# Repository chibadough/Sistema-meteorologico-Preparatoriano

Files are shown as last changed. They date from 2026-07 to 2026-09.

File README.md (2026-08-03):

# Sistema-meteorologico-Preparatoriano

Código de una estación meteorológica Balun Canan desarrollada por un grupo de estudiantes de preparatoria como parte de un proyecto STEM presentado para la Fundación MetLife y el movimiento STEM.

---

## Desarrolladores

Hardware (Programador Arduino, Diseño de circuitos y modelo 3D): ChibaDough (Juan Espinosa).
Software (Programador del sistema de almacenamiento de datos en SQL con Python en Raspberry Pi 4): Roberto Bonifaz.

---
# Español

## Descripción del Proyecto

Este proyecto consiste en una estación meteorológica educativa diseñada y programada por estudiantes de preparatoria con el objetivo de fomentar el aprendizaje científico, el monitoreo ambiental y el desarrollo tecnológico.

El sistema recopila datos atmosféricos y ambientales en tiempo real utilizando sensores compatibles con Arduino.  
Su propósito es demostrar cómo los sistemas embebidos de bajo costo pueden utilizarse para monitoreo climático, experimentación científica e investigación educativa.

La estación fue desarrollada como un prototipo funcional capaz de medir condiciones ambientales tanto en exteriores como en zonas de sombra para realizar comparaciones y pruebas.

Este repositorio contiene el código fuente utilizado para leer sensores, procesar información ambiental y mostrar telemetría mediante comunicación Serial.

---

## Características

- Monitoreo de presión atmosférica mediante BME280
- Medición de temperatura ambiental
- Monitoreo de humedad relativa
- Medición de velocidad del viento y direccion.
- Mediciones pluviales
- Comparación entre temperatura exterior y en sombra
- Salida de telemetría en tiempo real por Serial
- Arquitectura modular basada en Arduino

---

## Tecnologías y Hardware

El proyecto utiliza:

- Microcontrolador compatible con Arduino
- Sensor atmosférico BME280
- Sensores DHT11 de humedad y temperatura
- Bus de comunicación I2C
- Salida Serial para telemetría

---

## Librerías Utilizadas

Este proyecto utiliza las siguientes librerías de Arduino:

- `Wire.h`
- `Adafruit_BME280`
- `Adafruit_Sensor`
- `DHT`
- `DHT_U`

---

## Créditos

Agradecimientos especiales a los desarrolladores y mantenedores de las librerías de código abierto utilizadas en este proyecto:

- [Adafruit BME280 Library](https://github.com/adafruit/Adafruit_BME280_Library)
- [Adafruit Unified Sensor Library](https://github.com/adafruit/Adafruit_Sensor)
- [DHT Sensor Library by Adafruit](https://github.com/adafruit/DHT-sensor-library)
- [Arduino Wire Library Documentation](https://www.arduino.cc/reference/en/language/functions/communication/wire/)

Este proyecto no sería posible sin la comunidad open-source de Arduino y STEM.

---

## Propósito Educativo

Este repositorio fue creado principalmente para:

- Educación STEM
- Monitoreo ambiental
- Aprendizaje de sistemas embebidos
- Práctica de integración de sensores
- Experimentación científica
- Proyectos de ingeniería a nivel preparatoria

El proyecto fue desarrollado como un prototipo educativo, por lo que algunos sistemas e implementaciones pueden permanecer experimentales o simplificados.

---

## Equipo y Colaboración

Esta estación meteorológica fue desarrollada colaborativamente por un grupo de estudiantes de preparatoria interesados en ciencia, ingeniería, programación y tecnologías ambientales.

El proyecto fue creado como parte de una iniciativa educativa relacionada con:

- El movimiento STEM
- Programas de innovación científica y tecnológica
- Desarrollo de prototipos educativos para la Fundación MetLife

---

## Contribuciones

Las sugerencias, mejoras y comentarios son bienvenidos.

Posibles mejoras futuras incluyen:

- Dashboard web para monitoreo climático
- Sensores más precisos
- Soporte para tarjetas SD

---

# English

## Project Description

This project is the Balun Canan weather station designed and programmed by high school students to promote scientific learning, environmental monitoring, and STEM development.

The system collects real-time atmospheric and environmental data using Arduino-compatible sensors.  
Its purpose is to demonstrate how low-cost embedded systems can be used for climate monitoring, scientific experimentation, and educational research.

The station was developed as a functional prototype capable of measuring environmental conditions both outdoors and in shaded areas for comparison and testing purposes.

This repository contains the source code used to read sensor data, process environmental information, and display telemetry through Serial communication.

---

## Developers

Hardware (Arduino programming, circuit design, and 3D modeling): ChibaDough (Juan Espinosa).
Software (Programming the SQL data storage system using Python on Raspberry Pi 4): Roberto Bonifaz.

---

## Features

- Atmospheric pressure monitoring using BME280
- Environmental temperature measurement
- Relative humidity monitoring
- Wind speed and direction measurement
- Rainfall measurement
- Outdoor and shaded temperature comparison
- Real-time Serial telemetry output
- Arduino-based modular architecture

---

## Technologies and Hardware

The project uses:

- Arduino-compatible microcontroller
- BME280 atmospheric pressure sensor
- DHT11 humidity and temperature sensors
- I2C communication bus
- Serial telemetry output

---

## Libraries Used

This project uses the following Arduino libraries:

- `Wire.h`
- `Adafruit_BME280`
- `Adafruit_Sensor`
- `DHT`
- `DHT_U`

---

## Credits

Special thanks to the developers and maintainers of the open-source libraries used in this project:

- [Adafruit BME280 Library](https://github.com/adafruit/Adafruit_BME280_Library)
- [Adafruit Unified Sensor Library](https://github.com/adafruit/Adafruit_Sensor)
- [DHT Sensor Library by Adafruit](https://github.com/adafruit/DHT-sensor-library)
- [Arduino Wire Library Documentation](https://www.arduino.cc/reference/en/language/functions/communication/wire/)

This project would not be possible without the open-source Arduino and STEM communities.

---

## Educational Purpose

This repository was created mainly for:

- STEM education
- Environmental monitoring
- Embedded systems learning
- Sensor integration practice
- Scientific experimentation
- High school engineering projects

The project was developed as an educational prototype, so some systems and implementations may remain experimental or simplified.

---

## Team and Collaboration

This weather station was developed collaboratively by a group of high school students interested in science, engineering, programming, and environmental technologies.

The project was created as part of an educational initiative connected to:

- The STEM movement
- Scientific and technological innovation programs
- Educational prototype development for the MetLife Foundation

---

## Contributions

Suggestions, improvements, and feedback are welcome.

Possible future improvements include:

- Online weather monitoring dashboard
- More accurate sensors
- SD card storage support

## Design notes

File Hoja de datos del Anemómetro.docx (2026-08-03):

Sistema de Medición con Anemómetro

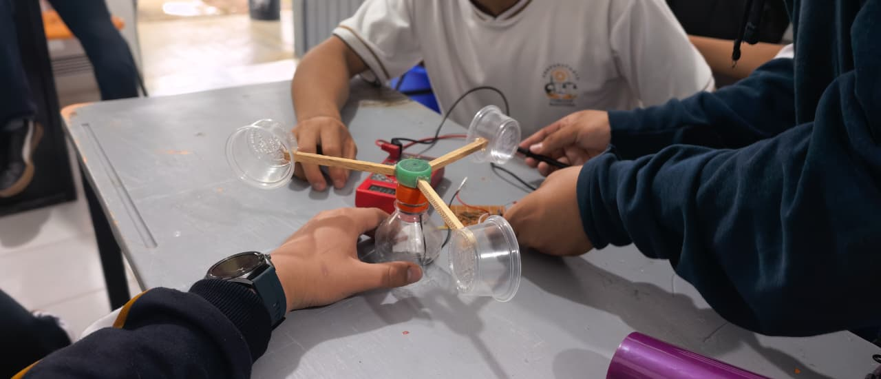
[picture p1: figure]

1. Resumen

Este documento especifica la integración del anemómetro analógico basado en un motor electrico para la medición de la velocidad del aire. A partir de los datos experimentales capturados (AnlogoutAnemometro vs VelAire), se aplica la función de transferencia definida para calcular directamente la velocidad del viento en función de la lectura analógica.

2. Datos de Calibración Registrados

De acuerdo con las mediciones experimentales del archivo anemometro.xlsx:

Índice | Lectura Analógica (l1 / AnlogoutAnemometro) | Velocidad del Aire (VelAire - KM/H)
1 | 13 | 28.2
2 | 17 | 37.7
3 | 23 | 44.0
4 | 27 | 46.1

3. Función de Transferencia / Ecuación del Sensor

La conversión de la señal analógica leída por el microcontrolador a la velocidad del aire utiliza la siguiente ecuación:

vel=0.78⋅l1-5.46

Donde:

vel: Velocidad del aire calculada.

Pendiente ( m ): 0.78

Término independiente ( b ): -5.46

3.1 Termino Independiente.

La aplicación de anemómetros basados en motores es practico y barato, pero puede tener ciertas implicaciones. Como voltajes parásitos mientras el anemómetro está en reposo, el termino independiente (b) es una resta que se hace midiendo el pico máximo de ese voltaje para que cuando eso suceda represente 0. No es necesario, pero hay que tomarlo en cuenta. Como también que gracias al termino independiente, pueden representarse valores negativos. Así que, si no es muy necesario no lo hagas, y si lo vas a colocar, asegura de promediar cada 10 valores o reducir la velocidad de muestreo para que solo se represente valores congruentes al tanteo.

4. Código de Implementación (Arduino / Microcontroladores)

A continuación se presenta el código de lectura y cálculo estructurado utilizando la función del anemómetro:

C++

/*

* Documentación de Código: Medición de Velocidad con Anemómetro

* Ecuación aplicada: vel = 0.78 * l1 - 5.46

*/

// Definición de Pines

const int Ane = A0; // Pin de entrada analógica del anemómetro

// Variables de medición

int l1 = 0; // Valor bruto leído por analogRead

float vel = 0.0; // Velocidad calculada

void setup() {

Serial.begin(115200);

pinMode(Ane, INPUT);

}

void loop() {

// 1. Lectura de la entrada analógica

l1 = analogRead(Ane);

// 2. Aplicación de la función de transferencia

vel = 0.78 * l1 - 5.46;

// 3. Imprimir resultados por Puerto Serie

Serial.print("Lectura ADC (l1): ");

Serial.print(l1);

Serial.print(" | Velocidad: ");

Serial.print(vel, 2);

Serial.println(" km/h");

delay(1000); // Frecuencia de actualización

}

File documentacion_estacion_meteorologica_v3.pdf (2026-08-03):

# Documentación Técnica del Proyecto

Estación Meteorológica Educativa Integrada (Arduino + Raspberry Pi + MySQL)

Proyecto: Monitoreo Ambiental
STEM

Nivel: Preparatoria /
Bachillerato

Arquitectura: Arduino (Adquisición) & Python/MySQL (Procesamiento)

### 1. Resumen General del Proyecto

Descripción: Este proyecto consiste en una estación meteorológica educativa diseñada y programada por estudiantes de preparatoria con el objetivo de fomentar el aprendizaje científico, el monitoreo ambiental y el desarrollo tecnológico.

El sistema recopila datos atmosféricos y ambientales en tiempo real utilizando un microcontrolador Arduino para la captura de variables analógicas/digitales y una computadora de placa única (Raspberry Pi/Linux) para el cómputo avanzado, almacenamiento persistente en base de datos MySQL y registro local CSV.

### 2. Objetivos y Alcance

Educativo & STEM: Demostrar cómo los sistemas embebidos de bajo costo pueden utilizarse para monitoreo climático, experimentación científica e investigación en el aula.

Redundancia y Robustez: Implementar tolerancia a fallos en sensores críticos (como conmutación automática entre sensores DHT11 primario y secundario).

Medición Multivariable: Medición en exteriores y sombra de temperatura, humedad, presión atmosférica, velocidad del viento, precipitación pluvial acumulada y calidad del aire (PPM).

Integración de Software: Protocolo de comunicación Serial entre microcontrolador y servidor Python con persistencia en MySQL (balun_canan).

•

•

•

•

Estación Meteorológica Educativa | Proyecto STEM | Página 1 de 6

### 3. Arquitectura del Hardware y Sensores

Componente / Sensor | Interfaz / Pin | Variable Medida | Función / Observaciones
Arduino Microcontroller | Serial USB (9600 baud) | Adquisición en tiempo real | Lee sensores de campo, procesa pulsos e interrupciones, envía trama CSV por Serial.
BME280 (I2C) | I2C (0x76 / Bus 1) | Temp (°C), Presión (hPa), Humedad (%) | Sensor de alta precisión presente en módulo Arduino y servidor Raspberry Pi.
DHT11 (x2) | Digital Pin 5 (Pri) / Pin 8 (Sec) | Temperatura / Humedad Relativa | Sistema de respaldo con reinicio de alimentación mediante transistores/relés (Pins 7 y 4).
Anemómetro Analógico | Pin Analógico A3 | Velocidad del Viento (m/s o km/h) | Ecuación de calibración lineal aplicada: vel = 0.78 × l1 − 5.46.
Pluviómetro de Balancín | Pin Digital 3 (INT) | Precipitación acumulada (mm) | Mapeo por interrupción (FALLING). Calibrado a 0.3 mm/pulso con anti-rebote (300 ms).
Sensor de Lluvia | Pin Analógico A2 | Detección cualitativa de lluvia | Identifica inicio de lluvia (≥200) o lluvia definitiva (≥600).
MQ-135 | Pin Analógico A1 | Calidad del aire / Gases (PPM) | Cálculo de concentración de gases compensado por temperatura y humedad.

### 4. Código Arduino (`estacion_meteorologica.ino`)

Arduino C++ - Captura y Control de Sensores

#include <MQ135.h>

#include <Adafruit_BME280.h>

#include <Wire.h>

#include <DHT.h>

// Definición de Pines
const int pinV = 7;
const int pinV2 = 4;
const int Ane = A3;
const int sensorA = A2;
const int pluv = 3;
#define PIN_MQ135 A1

#define DHTPIN 5

#define DHTPIN1 8

#define DHTTYPE DHT11

DHT dht(DHTPIN, DHTTYPE);
DHT dht1(DHTPIN1, DHTTYPE); Adafruit_BME280 bme;
MQ135 mq135_sensor(PIN_MQ135);

// Variables Pluviómetro
volatile int contadorPluv = 0;
volatile unsigned long ultimoPulso = 0; volatile unsigned long ultimoPulsoReal = 0; const float mmPulso = 0.3;
const int umbralTiempo = 300; // Anti-rebote (ms)

bool advertencia1 = false;

Estación Meteorológica Educativa | Proyecto STEM | Página 2 de 6

bool advertencia2 = false;

void setup() {
Serial.begin(9600);
dht.begin();
dht1.begin();
Wire.begin();

bme.begin(0x76);

pinMode(pinV, OUTPUT);
pinMode(pinV2, OUTPUT);
pinMode(Ane, INPUT);
pinMode(sensorA, INPUT);
pinMode(pluv, INPUT_PULLUP);

digitalWrite(pinV, HIGH);
digitalWrite(pinV2, HIGH);

attachInterrupt(digitalPinToInterrupt(pluv), contarLluvia, FALLING); }

void contarLluvia() {
unsigned long ahora = millis();
if (ahora - ultimoPulso > umbralTiempo) { contadorPluv++;
ultimoPulso = ahora;
ultimoPulsoReal = ahora;
}
}

void loop() {
float lecturA = analogRead(sensorA);

noInterrupts();
int pulsos = contadorPluv;
unsigned long ultimo = ultimoPulsoReal; interrupts();

if (millis() - ultimo > 30000UL) { noInterrupts();
contadorPluv = 0;
interrupts();
pulsos = 0;
}

float mmTotal = pulsos * mmPulso;

// Manejo de Respaldo DHT11
float tem1 = dht.readTemperature();
float hum1 = dht.readHumidity();

if ((isnan(tem1) || isnan(hum1)) && !advertencia1) { advertencia1 = true;
Serial.println("Reiniciando DHT11 primario..."); digitalWrite(pinV, LOW);
delay(2000);
digitalWrite(pinV, HIGH);
delay(2000);
tem1 = dht.readTemperature();
hum1 = dht.readHumidity();
} else if ((isnan(tem1) || isnan(hum1)) && advertencia1 && !advertencia2) { Serial.println("Cambiando a DHT11 de repuesto...");
advertencia2 = true;
digitalWrite(pinV2, HIGH);
tem1 = dht1.readTemperature();
hum1 = dht1.readHumidity();
Estación Meteorológica Educativa | Proyecto STEM | Página 3 de 6

} else if (isnan(tem1) || isnan(hum1)) { Serial.println("PROBLEMA CON DHT11: REVISAR"); } else {
digitalWrite(pinV, HIGH);
digitalWrite(pinV2, HIGH);
}

float temp = bme.readTemperature(); float pres = bme.readPressure() / 100.0;

int l1 = analogRead(Ane);
float vel = 0.78 * l1 - 5.46;
if (vel < 0) vel = 0; // Evitar valores negativos por descalibración en reposo

float ppm = mq135_sensor.getCorrectedPPM(temp, hum1);

// Formato Serial CSV: Temp_BME, Temp_DHT, Presion, Vel_Viento, Precipitacion, Humedad_DHT, PPM Serial.print(temp); Serial.print(",");
Serial.print(tem1); Serial.print(",");
Serial.print(pres); Serial.print(",");
Serial.print(vel); Serial.print(","); Serial.print(mmTotal); Serial.print(","); Serial.print(hum1); Serial.print(","); Serial.println(ppm);

delay(5000);
}

### 5. Código Python (`programa_6.py`)

Python 3 - Cliente de Procesamiento, CSV y MySQL

import time
from datetime import datetime
import math
import os
import serial
from smbus2 import SMBus
from bme280 import BME280
import mysql.connector

# ===================================== # CÁLCULOS METEOROLÓGICOS

# =====================================

def punto_rocio(temp, hum):
a = 17.27
b = 237.7
alpha = ((a * temp) / (b + temp)) + math.log(hum / 100.0) return (b * alpha) / (a - alpha)

def sensacion_termica(temp, hum):
return (-8.784695 +
1.61139411 * temp +
2.338549 * hum -
0.14611605 * temp * hum -
0.012308094 * (temp**2) -
0.016424828 * (hum**2) +
0.002211732 * (temp**2) * hum + 0.00072546 * temp * (hum**2) -0.000003582 * (temp**2) * (hum**2))

# Configuración de Sensores

bus = SMBus(1)
Estación Meteorológica Educativa | Proyecto STEM | Página 4 de 6

bme280 = BME280(i2c_dev=bus)

# Conexión Base de Datos

db_pass = os.environ.get("DB_PASSWORD", "3and1D0*") db = mysql.connector.connect(
host="localhost",
user="root",
password=db_pass,
database="balun_canan"
)
cursor = db.cursor()

# Conexión Serial Arduino

try:
ser = serial.Serial('/dev/ttyACM0', 9600, timeout=2) time.sleep(2)
except Exception as e:
print(f" Error al abrir puerto Serial: {e}")
ser = None

def leer_arduino():
if ser is None:
return None, None, None, None, None, None, None

try:
line = ser.readline().decode('utf-8').strip() if line:
valores = line.split(',')
if len(valores) == 7:
temp_A = float(valores[0]) temp_ext_A = float(valores[1]) presion_A = float(valores[2]) anemometro = float(valores[3]) precipitacion = float(valores[4])
humedad_A = float(valores[5])
ppm_A = float(valores[6])
return temp_A, temp_ext_A, presion_A, anemometro, precipitacion, humedad_A, ppm_A else:
print(f" Trama incompleta. Recibidos: {len(valores)} campos")
except Exception as e:
print(f" Error lectura Serial: {e}")

return None, None, None, None, None, None, None

# Bucle Principal

print('Comienzo de lectura de estación meteorológica...') contador = 0

with open('datosa.csv', 'a', buffering=1) as f:
while True:
try:
temperatura = bme280.get_temperature() presion = bme280.get_pressure()
humedad = bme280.get_humidity()

dew = punto_rocio(temperatura, humedad)
heat = sensacion_termica(temperatura, humedad)

temp_A, temp_ext_A, presion_A, anemometro, precipitacion, humedad_A, ppm_A = leer_arduino()

now = datetime.now()
fecha_hora = now.strftime("%Y-%m-%d %H:%M:%S")
print(f"[{fecha_hora}] Local BME280: {temperatura:.2f}°C | {presion:.2f} hPa | {humedad:.2f}%")
print(f" | → Rocío: {dew:.2f}°C | Sensación: {heat:.2f}°C")
print(f" | → Arduino: T={temp_A}, TExt={temp_ext_A}, P={presion_A}, Wind={anemometro},
Rain={precipitacion}")
Estación Meteorológica Educativa | Proyecto STEM | Página 5 de 6

if -40 < temperatura < 85 and 300 < presion < 1100: f.write(f"{fecha_hora},{temperatura:.2f},{presion:.2f},{humedad:.2f},{dew:.2f},{heat:.2f}," f"{temp_A},{temp_ext_A},{presion_A},{anemometro},{precipitacion},{humedad_A},{ppm_A} \n")

db.ping(reconnect=True)
sql = ("INSERT INTO Datos_Arduino "
"(fecha, temperatura, presion, humedad, punto_rocio, sensacion_termica, " "temp_A, temp_ext_A, presion_A, anemometro, precipitacion, humedad_A, ppm_A) " "VALUES (%s, %s, %s, %s, %s, %s, %s, %s, %s, %s, %s, %s, %s)")

valores_db = (fecha_hora, temperatura, presion, humedad, dew, heat,
temp_A, temp_ext_A, presion_A, anemometro, precipitacion, humedad_A, ppm_A)

cursor.execute(sql, valores_db)
contador += 1
if contador >= 10:
db.commit()
print(" Lote de 10 registros guardado en MySQL") contador = 0

except Exception as e:
print(" Error general en bucle:", e)

time.sleep(60) # Intervalo de lectura sugerido: 60 segundos

### 6. Guía de Instalación y Puesta en Marcha

Configuración en Arduino: Instalar las librerías MQ135, Adafruit_BME280 y DHT en el IDE de Arduino y compilar el archivo .ino.

Creación de Base de Datos MySQL:

CREATE DATABASE balun_canan;
USE balun_canan;

CREATE TABLE Datos_Arduino (
id INT AUTO_INCREMENT PRIMARY KEY, fecha DATETIME,
temperatura FLOAT,
presion FLOAT,
humedad FLOAT,
punto_rocio FLOAT,
sensacion_termica FLOAT,
temp_A FLOAT,
temp_ext_A FLOAT,
presion_A FLOAT,
anemometro FLOAT,
precipitacion FLOAT,
humedad_A FLOAT,
ppm_A FLOAT
);

Ejecución del Servicio en Python:

pip install smbus2 matrix-bme280 mysql-connector-python pyserial python3 programa_6.py

1.

2.

3.

Estación Meteorológica Educativa | Proyecto STEM | Página 6 de 6

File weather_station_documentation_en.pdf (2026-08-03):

# Technical Project Documentation

Integrated Educational Weather Station (Arduino + Raspberry Pi + MySQL)

Project: Environmental STEM
Monitoring

Level: High School / K-12
STEM

Architecture: Arduino (Acquisition) & Python/MySQL (Processing)

### 1. Project Overview

Description: This project consists of an educational weather station designed and programmed by high school students to foster scientific learning, environmental monitoring, and technological development.

The system collects real-time atmospheric and environmental data using an Arduino microcontroller for analog/ digital sensor reading, along with a single-board computer (Raspberry Pi/Linux) for advanced computation, persistent storage in a MySQL database, and local CSV logging.

### 2. Objectives and Scope

Educational & STEM: Demonstrate how low-cost embedded systems can be utilized for climate monitoring, scientific experimentation, and classroom research.

Redundancy & Robustness: Implement fault tolerance for critical sensors (such as automatic failover switching between primary and backup DHT11 sensors).

Multivariable Measurement: Outdoor and shaded monitoring of temperature, humidity, atmospheric pressure, wind speed, accumulated rainfall, and air quality (PPM).

Software Integration: Serial communication protocol between the microcontroller and the Python server with data persistence in MySQL (balun_canan).

•

•

•

•

Educational Weather Station | STEM Project | Page 1 of 6

### 3. Hardware Architecture and Sensors

Component / Sensor | Interface / Pin | Measured Variable | Function / Remarks
Arduino Microcontroller | Serial USB (9600 baud) | Real-time acquisition | Reads field sensors, handles pulses and interrupts, sends CSV frame over Serial.
BME280 (I2C) | I2C (0x76 / Bus 1) | Temp (°C), Pressure (hPa), Humidity (%) | High-precision sensor located on both the Arduino module and the Raspberry Pi server.
DHT11 (x2) | Digital Pin 5 (Pri) / Pin 8 (Sec) | Temperature / Relative Humidity | Backup system with power reset controlled via transistors/relays (Pins 7 and 4).
Analog Anemometer | Analog Pin A3 | Wind Speed (m/s or km/ h) | Linear calibration equation applied: vel = 0.78 × l1 − 5.46.
Tipping Bucket Rain Gauge | Digital Pin 3 (INT) | Accumulated Rainfall (mm) | Mapped via hardware interrupt (FALLING). Calibrated to 0.3 mm/pulse with debouncing (300 ms).
Rainfall Sensor | Analog Pin A2 | Qualitative rain detection | Identifies rain onset (≥200) or definitive rain (≥600).
MQ-135 | Analog Pin A1 | Air Quality / Gas Concentration (PPM) | Gas concentration calculation compensated for ambient temperature and humidity.

### 4. Arduino Source Code (`estacion_meteorologica.ino`)

Arduino C++ - Sensor Acquisition and Control

#include <MQ135.h>

#include <Adafruit_BME280.h>

#include <Wire.h>

#include <DHT.h>

// Pin Definitions
const int pinV = 7;
const int pinV2 = 4;
const int Ane = A3;
const int sensorA = A2;
const int pluv = 3;
#define PIN_MQ135 A1

#define DHTPIN 5

#define DHTPIN1 8

#define DHTTYPE DHT11

DHT dht(DHTPIN, DHTTYPE);
DHT dht1(DHTPIN1, DHTTYPE); Adafruit_BME280 bme;
MQ135 mq135_sensor(PIN_MQ135);

// Rain Gauge Variables
volatile int contadorPluv = 0;
volatile unsigned long ultimoPulso = 0;
volatile unsigned long ultimoPulsoReal = 0;
const float mmPulso = 0.3;
const int umbralTiempo = 300; // Debounce threshold (ms)

bool advertencia1 = false;

bool advertencia2 = false;

void setup() {
Serial.begin(9600);
dht.begin();
dht1.begin();
Wire.begin();

bme.begin(0x76);

pinMode(pinV, OUTPUT);
pinMode(pinV2, OUTPUT);
pinMode(Ane, INPUT);
pinMode(sensorA, INPUT);
pinMode(pluv, INPUT_PULLUP);

digitalWrite(pinV, HIGH);
digitalWrite(pinV2, HIGH);

attachInterrupt(digitalPinToInterrupt(pluv), contarLluvia, FALLING); }

void contarLluvia() {
unsigned long ahora = millis();
if (ahora - ultimoPulso > umbralTiempo) { contadorPluv++;
ultimoPulso = ahora;
ultimoPulsoReal = ahora;
}
}

void loop() {
float lecturA = analogRead(sensorA);

noInterrupts();
int pulsos = contadorPluv;
unsigned long ultimo = ultimoPulsoReal; interrupts();

if (millis() - ultimo > 30000UL) { noInterrupts();
contadorPluv = 0;
interrupts();
pulsos = 0;
}

float mmTotal = pulsos * mmPulso;

// DHT11 Backup System Handling
float tem1 = dht.readTemperature();
float hum1 = dht.readHumidity();

if ((isnan(tem1) || isnan(hum1)) && !advertencia1) { advertencia1 = true;
Serial.println("Resetting primary DHT11..."); digitalWrite(pinV, LOW);
delay(2000);
digitalWrite(pinV, HIGH);
delay(2000);
tem1 = dht.readTemperature();
hum1 = dht.readHumidity();
} else if ((isnan(tem1) || isnan(hum1)) && advertencia1 && !advertencia2) { Serial.println("Switching to backup DHT11...");
advertencia2 = true;
digitalWrite(pinV2, HIGH);
tem1 = dht1.readTemperature();
hum1 = dht1.readHumidity();

} else if (isnan(tem1) || isnan(hum1)) { Serial.println("DHT11 ISSUE: CHECK SENSOR"); } else {
digitalWrite(pinV, HIGH);
digitalWrite(pinV2, HIGH);
}

float temp = bme.readTemperature(); float pres = bme.readPressure() / 100.0;

int l1 = analogRead(Ane);
float vel = 0.78 * l1 - 5.46;
if (vel < 0) vel = 0; // Avoid negative values due to offset at rest

float ppm = mq135_sensor.getCorrectedPPM(temp, hum1);

// Serial CSV Output: Temp_BME, Temp_DHT, Pressure, Wind_Speed, Rainfall, Humidity_DHT, PPM Serial.print(temp); Serial.print(",");
Serial.print(tem1); Serial.print(",");
Serial.print(pres); Serial.print(",");
Serial.print(vel); Serial.print(","); Serial.print(mmTotal); Serial.print(","); Serial.print(hum1); Serial.print(","); Serial.println(ppm);

delay(5000);
}

### 5. Python Source Code (`programa_6.py`)

Python 3 - Processing Client, CSV & MySQL

import time
from datetime import datetime
import math
import os
import serial
from smbus2 import SMBus
from bme280 import BME280
import mysql.connector

# ===================================== # METEOROLOGICAL CALCULATIONS

# =====================================

def punto_rocio(temp, hum):
a = 17.27
b = 237.7
alpha = ((a * temp) / (b + temp)) + math.log(hum / 100.0) return (b * alpha) / (a - alpha)

def sensacion_termica(temp, hum):
return (-8.784695 +
1.61139411 * temp +
2.338549 * hum -
0.14611605 * temp * hum -
0.012308094 * (temp**2) -
0.016424828 * (hum**2) +
0.002211732 * (temp**2) * hum + 0.00072546 * temp * (hum**2) -0.000003582 * (temp**2) * (hum**2))

# Sensor Setup

bus = SMBus(1)

bme280 = BME280(i2c_dev=bus)

# Database Connection

db_pass = os.environ.get("DB_PASSWORD", "3and1D0*") db = mysql.connector.connect(
host="localhost",
user="root",
password=db_pass,
database="balun_canan"
)
cursor = db.cursor()

# Arduino Serial Connection

try:
ser = serial.Serial('/dev/ttyACM0', 9600, timeout=2) time.sleep(2)
except Exception as e:
print(f" Error opening Serial port: {e}")
ser = None

def leer_arduino():
if ser is None:
return None, None, None, None, None, None, None

try:
line = ser.readline().decode('utf-8').strip() if line:
valores = line.split(',')
if len(valores) == 7:
temp_A = float(valores[0]) temp_ext_A = float(valores[1]) presion_A = float(valores[2]) anemometro = float(valores[3]) precipitacion = float(valores[4])
humedad_A = float(valores[5])
ppm_A = float(valores[6])
return temp_A, temp_ext_A, presion_A, anemometro, precipitacion, humedad_A, ppm_A else:
print(f" Incomplete frame received. Length: {len(valores)}")
except Exception as e:
print(f" Serial reading error: {e}")

return None, None, None, None, None, None, None

# Main Loop

print('Starting weather station data collection...') contador = 0

with open('datosa.csv', 'a', buffering=1) as f: while True:
try:
temperatura = bme280.get_temperature() presion = bme280.get_pressure()
humedad = bme280.get_humidity()

dew = punto_rocio(temperatura, humedad)
heat = sensacion_termica(temperatura, humedad)

temp_A, temp_ext_A, presion_A, anemometro, precipitacion, humedad_A, ppm_A = leer_arduino()

now = datetime.now()
fecha_hora = now.strftime("%Y-%m-%d %H:%M:%S")
print(f"[{fecha_hora}] Local BME280: {temperatura:.2f}°C | {presion:.2f} hPa | {humedad:.2f}%")
print(f" | → Dew Point: {dew:.2f}°C | Heat Index: {heat:.2f}°C")
print(f" | → Arduino: T={temp_A}, TExt={temp_ext_A}, P={presion_A}, Wind={anemometro},
Rain={precipitacion}")

if -40 < temperatura < 85 and 300 < presion < 1100: f.write(f"{fecha_hora},{temperatura:.2f},{presion:.2f},{humedad:.2f},{dew:.2f},{heat:.2f}," f"{temp_A},{temp_ext_A},{presion_A},{anemometro},{precipitacion},{humedad_A},{ppm_A} ")

db.ping(reconnect=True)
sql = ("INSERT INTO Datos_Arduino "
"(fecha, temperatura, presion, humedad, punto_rocio, sensacion_termica, " "temp_A, temp_ext_A, presion_A, anemometro, precipitacion, humedad_A, ppm_A) " "VALUES (%s, %s, %s, %s, %s, %s, %s, %s, %s, %s, %s, %s, %s)")

valores_db = (fecha_hora, temperatura, presion, humedad, dew, heat,
temp_A, temp_ext_A, presion_A, anemometro, precipitacion, humedad_A, ppm_A)

cursor.execute(sql, valores_db)
contador += 1
if contador >= 10:
db.commit()
print(" Batch of 10 records saved to MySQL") contador = 0

except Exception as e:
print(" Main loop error:", e)

time.sleep(60) # Suggested sampling interval: 60 seconds

### 6. Installation and Setup Guide

Arduino Configuration: Install the MQ135, Adafruit_BME280, and DHT libraries in the Arduino IDE and upload the .ino sketch.

MySQL Database Creation:

CREATE DATABASE balun_canan;
USE balun_canan;

CREATE TABLE Datos_Arduino (
id INT AUTO_INCREMENT PRIMARY KEY, fecha DATETIME,
temperatura FLOAT,
presion FLOAT,
humedad FLOAT,
punto_rocio FLOAT,
sensacion_termica FLOAT,
temp_A FLOAT,
temp_ext_A FLOAT,
presion_A FLOAT,
anemometro FLOAT,
precipitacion FLOAT,
humedad_A FLOAT,
ppm_A FLOAT
);

Python Service Execution:

pip install smbus2 matrix-bme280 mysql-connector-python pyserial python3 programa_6.py

1.

2.

3.

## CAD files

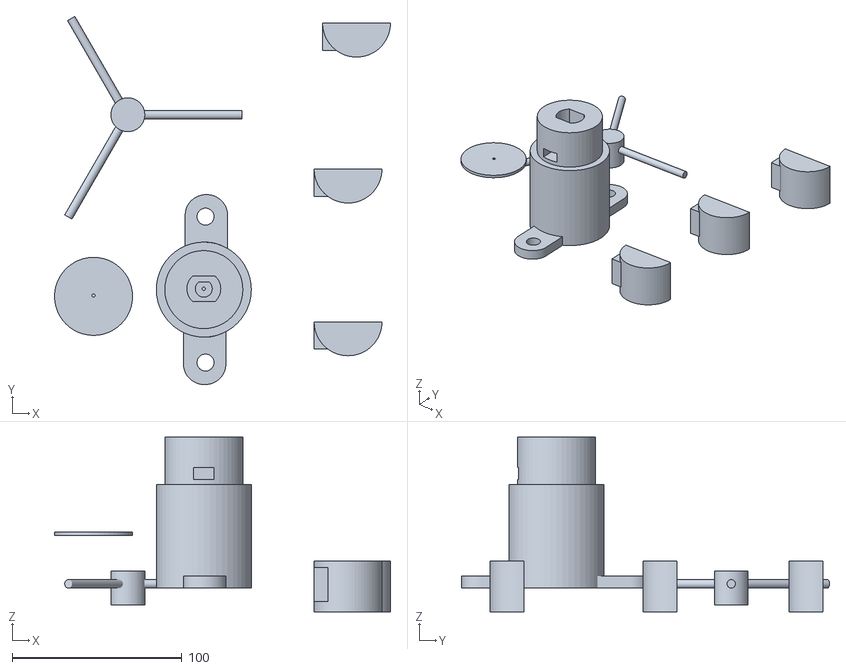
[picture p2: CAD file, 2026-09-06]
Anemometro por partes.stl
198.0 x 217.0 x 102.9

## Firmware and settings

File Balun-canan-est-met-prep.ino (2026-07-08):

//Hazme un favor y revisa el codigo mientas escuches:
//Super Ponybeat-Mirai Star! 
#include <MQ135.h>
#include <Adafruit_BME280.h>
#include <Wire.h>
#include <DHT.h>
#include <DHT_U.h>
int pinV =7;
int pinV2 =4;
int Ane = A3;
int l1;
float volt;
float vel;
int sensorA = A2;
float lecturA;

volatile int contadorPluv = 0;
volatile unsigned long ultimoPulso = 0;
volatile unsigned long ultimoPulsoReal = 0;

const float mmPulso = 0.3;


const int pluv = 3;
const int umbralTiempo = 300; 

float mmTotal = 0;


bool advertencia1 = false;
bool advertencia2 = false;

  #define DHTPIN 5
  #define DHTPIN1 8
  #define DHTTYPE DHT11


DHT dht(DHTPIN,DHTTYPE);
DHT dht1(DHTPIN1,DHTTYPE);

  float temp;
  float pres;

  
Adafruit_BME280 bme; 

#define PIN_MQ135 A1

MQ135 mq135_sensor(PIN_MQ135);


void setup() {
 Serial.begin(9600);
 dht.begin();
 dht1.begin();
 Wire.begin();
 bme.begin(0X76);
  pinMode(pinV,OUTPUT);
  pinMode(pinV2,OUTPUT);
  pinMode(Ane,INPUT);
  pinMode(pluv, INPUT_PULLUP);


attachInterrupt(
  digitalPinToInterrupt(pluv),
  contarLluvia,
  FALLING
);
  pinMode(sensorA,INPUT);
} 
void contarLluvia()
{
  unsigned long ahora = millis();

  if (ahora - ultimoPulso > umbralTiempo)
  {
    contadorPluv++;
    ultimoPulso = ahora;
    ultimoPulsoReal = ahora;
  }
}

void loop() {
lecturA = analogRead(sensorA);


noInterrupts();
int pulsos = contadorPluv;
unsigned long ultimo = ultimoPulsoReal;
interrupts();

if (millis() - ultimo > 30000UL) 
{
  noInterrupts();
  contadorPluv = 0;
  interrupts();

  pulsos = 0;
}

mmTotal = pulsos * mmPulso;

 
float tem1 = dht.readTemperature();
float hum1 = dht.readHumidity();
 temp = bme.readTemperature();
 pres = bme.readPressure() /100;

 l1 = analogRead(Ane);
 vel = 0.78 * l1 - 5.46; // funcion f(x) = 0.78(x) - 5.46 correspondiente al anemometro

 

 if((isnan(tem1) || isnan(hum1))&& advertencia1 == false){
 advertencia1 = true;
 Serial.println("Reinciando EL dht11");
 digitalWrite(pinV, LOW);
 delay(2000);
 digitalWrite(pinV, HIGH);
 delay(2000);
  tem1 = dht.readTemperature();
  hum1 = dht.readHumidity();
 } else if ((isnan(tem1) || isnan(hum1)) && advertencia1 == true && advertencia2 == false){
   Serial.println("Cambiando a dht11 de repuesto");
   advertencia2 = true;
   digitalWrite(pinV2, HIGH);
   tem1 = dht1.readTemperature();
   hum1 = dht1.readHumidity();
 } else if ((isnan(tem1) || isnan(hum1)) && advertencia2 == true){
 Serial.println("PROBLEMA CON EL DHT11: REVISAR");
 } else {
 digitalWrite(pinV, HIGH);
 digitalWrite(pinV2, HIGH);
 }

 if (isnan(temp) || isnan(pres)){
  Serial.println("ERROR CON EL BME280: REVISAR PUESTO QUE NO HAY REPUESTO");
 }

  Serial.print(temp);
  Serial.print(",");
  Serial.print(tem1);
  Serial.print(",");
  Serial.print(pres);
   Serial.print(",");
  Serial.print(vel);
   Serial.print(",");
  Serial.print(mmTotal);
   Serial.print(",");

if (lecturA >= 200){
  Serial.println("===ESTA EMPEZANDO A LLOVER===");
} else if(lecturA >= 600){
  Serial.println("===DEFINITAVEMENTE ESTA LLOVIENDO===");
} else if (lecturA == 0 && mmTotal >= 0.66){
  Serial.println("===REVISAR EL SENSOR DE LLUVIA O POSIBLE MOVIMIENTO EN FALSO DEL BALANCIN DEL PLUVIOMETRO===");
}

  Serial.print(hum1);
   Serial.print(",");

float rzero = mq135_sensor.getRZero();
  float correctedRZero = mq135_sensor.getCorrectedRZero(temp, hum1);
  float resistance = mq135_sensor.getResistance();
  float ppm = mq135_sensor.getPPM();
  float correctedPPM = mq135_sensor.getCorrectedPPM(temp, hum1);

  Serial.println(ppm);

 delay(5000);

 }

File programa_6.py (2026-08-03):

                  programa_6.py                               
import time
from datetime import datetime
import math
import os
import serial
from smbus2 import SMBus
from bme280 import BME280
import mysql.connector

# =====================================
# FUNCIONES METEOROLOGICAS
# =====================================

def punto_rocio(temp, hum):
    a = 17.27
    b = 237.7
    alpha = ((a * temp) / (b + temp)) + math.log(hum / 100.0)
    return (b * alpha) / (a - alpha)

def sensacion_termica(temp, hum):
    return (-8.784695 +
            1.61139411 * temp +
            2.338549 * hum +
            -0.14611605 * temp * hum +
            -0.012308094 * temp**2 +
            -0.016424828 * hum**2 +
            0.002211732 * temp**2 * hum +
            0.00072546 * temp * hum**2 +
            -0.000003582 * temp**2 * hum**2)

# =====================================
# CONFIGURACIÓN DE SENSORES Y BD
# =====================================

# Sensor BME280
bus = SMBus(1)
bme280 = BME280(i2c_dev=bus)

# Conexión Base de Datos
db = mysql.connector.connect(
    host="localhost",
    user="root",
    password="3and1D0*",  # ✅ Se recomienda usar os.environ.get("DB_PASSWORD")
    database="balun_canan"
)
cursor = db.cursor()

# Conexión Arduino Serial
try:
    ser = serial.Serial('/dev/ttyACM0', 9600, timeout=1)
    time.sleep(2)  # Esperar a que Arduino reinicie
except Exception as e:
    print(f"❌ No se pudo abrir el puerto serial: {e}")
    ser = None

# =====================================
# LECTURA DE ARDUINO
# =====================================

def leer_arduino():
 if ser is None:
        return None, None, None, None, None, None, None

    try:
        line = ser.readline().decode('utf-8').strip()
        if line:
            valores = line.split(',')
            if len(valores) == 7:
                print(f"📥 Datos recibidos Arduino: {line}")
                temp_A = float(valores[0])
                temp_ext_A = float(valores[1])
                presion_A = float(valores[2])
                anemometro = float(valores[3])
                precipitacion = float(valores[4])
                humedad_A = float(valores[5])
                ppm_A = float(valores[6])

                return temp_A, temp_ext_A, presion_A, anemometro, precipitacion>
            else:
                print(f"⚠️ Datos incompletos. Esperados 7, llegaron {len(valores>
    except ValueError as ve:
        print("❌ Error al convertir dato de Arduino a float:", ve)
    except Exception as e:
        print("❌ Error inesperado en lectura Serial:", e)

    return None, None, None, None, None, None, None

# =====================================
# BUCLE PRINCIPAL
# =====================================

print('Comienzo de lectura en 3 segundos...')
time.sleep(3)

contador = 0

with open('datosa.csv', 'a', buffering=1) as f:
  while True:
        try:
            # 1. Lectura BME280
            temperatura = bme280.get_temperature()
            presion = bme280.get_pressure()
            humedad = bme280.get_humidity()

            # 2. Cálculos Meteorológicos
            dew = punto_rocio(temperatura, humedad)
            heat = sensacion_termica(temperatura, humedad)

            # 3. Lectura Arduino (¡Ahora asigna los datos reales!)
            temp_A, temp_ext_A, presion_A, anemometro, precipitacion, humedad_A, ppm_A = leer_arduino()

            # 4. Fecha y Hora
            now = datetime.now()
            fecha_hora = now.strftime("%Y-%m-%d %H:%M:%S")

            # 5. Monitor Serial (Consola)
            print(f"{fecha_hora} | BME280: {temperatura:.2f}°C | {presion:.2f} hPa | {humedad:.2f}%")
            print(f"   → Rocío: {dew:.2f}°C | Sensación: {heat:.2f}°C")
            print(f"   → Arduino: Temp={temp_A}, TempExt={temp_ext_A}, Pres={presion_A}, Ane={anemometro}, Prec={precipitacion}, Hum={humedad_A}, PPM={ppm_A}")

            # 6. Validación de Datos del BME280
            if -40 < temperatura < 85 and 300 < presion < 1100:

                # Guardar en CSV
                f.write(f"{fecha_hora},{temperatura:.2f},{presion:.2f},{humedad:.2f},{dew:.2f},{heat:.2f},"
                        f"{temp_A},{temp_ext_A},{presion_A},{anemometro},{precipitacion},{humedad_A},{ppm_A}\n")
                f.flush()

                # Reconexión Base de Datos si se pierde
                db.ping(reconnect=True)

                # Ajustamos el SQL. Asegúrate de que las columnas coincidan exactamente en cantidad con los %s
                sql = """
                INSERT INTO Datos_Arduino 
                (fecha, temperatura, presion, humedad, punto_rocio, sensacion_termica, 
 temp_A, temp_ext_A, presion_A, anemometro, precipitacion, humedad_A, ppm_A) 
                VALUES (%s, %s, %s, %s, %s, %s, %s, %s, %s, %s, %s, %s, %s)
                """

                valores_db = (
                    fecha_hora, temperatura, presion, humedad, dew, heat,
                    temp_A, temp_ext_A, presion_A, anemometro, precipitacion, humedad_A, ppm_A
                )

                cursor.execute(sql, valores_db)

                # Control del Commit cada 10 registros
                contador += 1
                if contador >= 10:
                    db.commit()
                    print("¡Lote de 10 registros guardado en la Base de Datos!")
                    contador = 0

            else:
                print(" Dato BME280 fuera de rango seguro.")

        except Exception as e:
            print(" Error general en el bucle:", e)

        time.sleep(900)

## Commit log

2026-05-07 Add files via upload
    Esta es la primera parte del codigo para la estacion metorologica.
    Usa:
    DHT11
    BM280
2026-05-20 Update Balun-canan-est-met-prep.ino
    *Actualizaciones*
    Se implemento un sistema de reinicio para el dht11 que conecta y desconecta el pin de voltaje (el pin 7), siempre cuando envié valores "isnan", al igual que se mejoro la forma en la que los datos aparecen en el monitor serial.
    *upatades*
    A reset system was implemented for the dht11 that connects and disconnects the voltage pin (pin 7) whenever it sends "isnan" values, and the way data appears on the serial monitor was also improved.
    19/05/26
    [Balun-canan-est-met-prep.ino]
2026-05-21 Update Balun-canan-est-met-prep.ino
    *actualizacion*
    se introdujo un sistema de aviso cuando el dht11 falle, cuando esto suceda se reemplazará con otro de respaldo y en caso ambos fallen el sistema manda un aviso de revision. por otra parte el bmp280 tiene un sistema similar, pero este simplemente manda el aviso a revision puesto que no se cuenta con un reemplazo por el momento.
    *Update*
    A notification system has been introduced to alert users when the DHT11 fails. When this happens, it will be replaced with a backup unit, and if both fail, the system will send a service notification. The BMP280 has a similar system, but it simply sends a service notification since a replacement is not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
    [Balun-canan-est-met-prep.ino]
2026-06-02 Update Balun-canan-est-met-prep.ino
    Esp:
    Para resultados reales, cambiamos el BMP280 por el BME280 y eso quiere decir que también cambiamos la librería.
    Eng:
    For real-world results, we changed the BMP280 to the BME280, and that means we also changed the library.
2026-06-03 Update Balun-canan-est-met-prep.ino
    Se implemento la funcion de medicion de precipitacion con un pluviometro de balancin (MISOL) y un indicador basico de lluvia
    The precipitation medicine function is implemented with a balance rain gauge (MISOL) and a basic rainfall indicator.
    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
2026-06-10 Update Balun-canan-est-met-prep.ino
    ESP:
    Se corrigio el codigo del pluviometro basandose en el video de Mechatronics : https://www.youtube.com/watch?v=hvD2rsqDduU, se instalo un mq135
    [Balun-canan-est-met-prep.ino]
2026-06-10 Update Balun-canan-est-met-prep.ino
    modificacion de ultimo momento del serial plotter
2026-06-12 Modelo 3D de la verison FD/3D model of the FD version
2026-07-08 Update Balun-canan-est-met-prep.ino
    La ultima actualizacion es nada mas un ajuste a los datos que manda el serial. ahora solo son los datos sin ningun identificador.
2026-08-03 Archivos no subidos
    Subo el archivo .fzz que se uso para el diseño de la circuiteria del ¨datalogger¨ que usamos. Tenemos planes de actualizar nuestra plataforma de Arduino Uno a Arduino Mega. Al igual que el programa d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
    [EstacionMBalunC2026Circuito.fzz]
2026-08-03 Update README.md
    Cambio en la descripcion
2026-08-03 Documentación (EN-ES)
    ES:
    Gemini hizo un mal trabajo haciendo la documentacion, corrigio cosas que no debia al codigo. Por eso pido una disculpa por usar IA en esta ocasion, todo el codigo del arduino, esquema electrico y 3d se hizo sin usar IA.
    EN:
    Gemini did a poor job with the documentation and made changes to the code that shouldn't have been made. I apologize for using AI in this instance; the entire Arduino code, circuit schematic, and 3D design were created without using AI.
2026-08-03 Hoja de datos del anemometro
2026-09-06 Archivos gerber PCB
2026-09-06 Modelo 3d del anemometro (aun no impreso)
    [Anemometro por partes.stl]
